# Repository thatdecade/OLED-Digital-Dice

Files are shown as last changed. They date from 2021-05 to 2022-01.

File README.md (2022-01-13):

# OLED-Digital-Dice

This project is based on the work of Joe Coburn for the original design and Fernando Hernandez (Dsk001) for the Wemos version.

This Electronic Die has the capability to swap between a coin and die with 4, 6, 8, 10, 12, and 20 sides and also a double 6 sided. Useful for table top gaming, or dice games that require two 6 sided die.

This version adds:
* Button debouncing
* Fixed randomizer
* Battery monitoring
* Shake sensor for dice rolls (Tilt switch)
* Auto Power Off (Deep Sleep)
* Neopixels
* Magic 8 Ball
* Supports both I2C and SPI displays

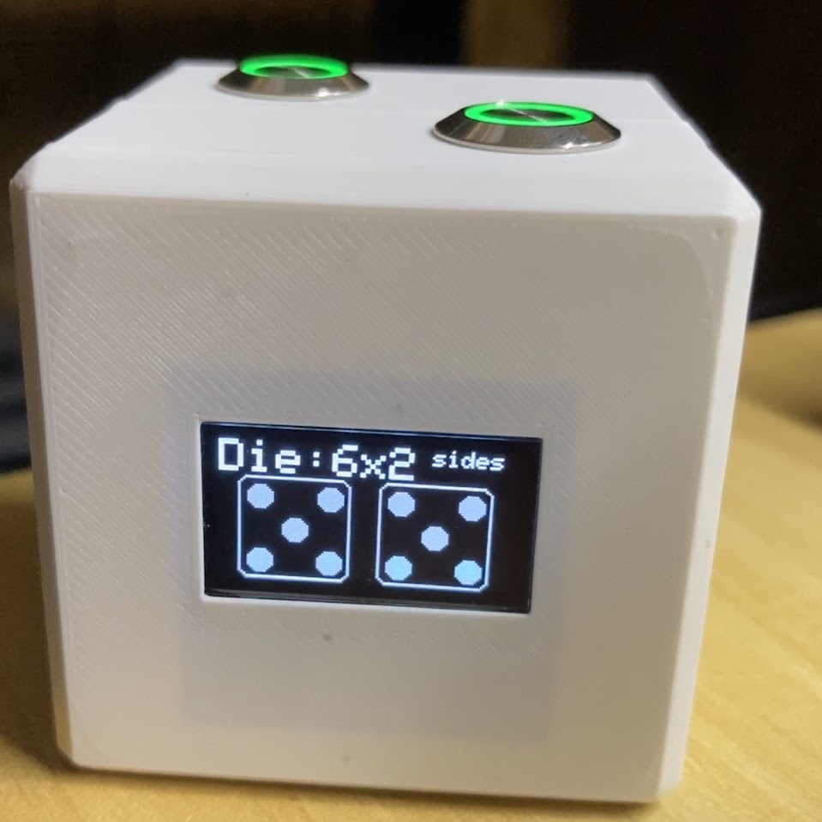
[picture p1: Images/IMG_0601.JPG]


Sources:
* 2017 Joe Coburn https://www.makeuseof.com/tag/roll-style-diy-electronic-d20/
* 2018 Tomas Carlsson (TomasC62) https://www.instructables.com/Arduino-Oled-Dice/
* 2021 Fernando Hernandez (Dsk001) https://www.prusaprinters.org/prints/66933-electronic-dice
* 2021 Joe Larson (3D Printing Professor) https://www.prusaprinters.org/prints/70261-electronic-dice-with-8-ball-function

# Hardware Used:

* 1 x D1 Mini (ESP8266, WiFi capable) https://amzn.to/3fCb4l7
* 1 x 0.96" I2C IIC SPI Serial 128x64 OLED screen https://amzn.to/3fxuOpV
* 2 x 12mm Push Buttons (LED optional) https://amzn.to/3p69FGo
* 2 x Metal Ball Tilt Switches (optional) https://amzn.to/34mlJKk

For battery operation (optional):

* 1 x Wemos D1 Battery Shield https://amzn.to/3c98Rvk
* 1 x 500mAh Lipo 
* 1 x 12mm LED Latching Push Button https://amzn.to/3uBmppL

We are a participant in the Amazon Services LLC Associates Program, an affiliate advertising program designed to provide a means for us to earn fees by linking to Amazon.com and affiliated sites.

# Printing:

Some openscad files are included in the project.  They assume you have downloaded the source files from https://www.prusaprinters.org/prints/66933-electronic-dice

* oled_face_mod.stl - The front shell oled area is trimmed to make it easier to fit.
* battery_back_mod.stl - The back shell includes cutaways for the battery shield, second usb connector, and a on/off push button.

# Pin References:

|Signal|In Type / Output Type|Label|GPIO|Input|Output|Notes|
|---|---|---|---|---|---|---|
|Deep Sleep Exit|Wire to RST|D0|GPIO16|no interrupt|no PWM or I2C support|HIGH at boot, used to wake up from deep sleep|
|Display SCL|I2C|D1|GPIO5|OK|OK|often used as (I2C)|
|Display SDA|I2C|D2|GPIO4|OK|OK|often used as (I2C)|
|Roll Button|Active Low Input|D3|GPIO0|pulled up|OK|connected to FLASH button, boot fails if pulled LOW|
|Die Button|Active High Input|D4|GPIO2|pulled up|OK|HIGH at boot, connected to on-board LED, boot fails if pulled LOW|
|Tilt Sensor 1|Active High Interrupt|D5|GPIO14|OK|OK|SPI (SCLK)|
|Roll LED|Active High Output|D6|GPIO12|OK|OK|SPI (MISO)|
|Neopixel Data|Data Output|D7|GPIO13|OK|OK|SPI (MOSI)|
|Dice LED|Active High Output|D8|GPIO15|pulled to GND|OK|SPI (CS), Boot fails if pulled HIGH|
|Tilt Sensor 2|Active High Interrupt|RX|GPIO3|OK|RX pin|HIGH at boot|
|||TX|GPIO1|TX pin|OK|HIGH at boot, debug output at boot, boot fails if pulled LOW|
|Battery Monitor|Analog Input|A0|ADC0|Analog Input|X||

Source: https://randomnerdtutorials.com/esp8266-pinout-reference-gpios/

# Assembly:

Wire up the following:

 *  D2(SDA), D1(SCL) to OLED
 *  D0 to RST
 *  D3 to Button (ROLL) to Ground
 *  D4 to Button (DIE) to 3.3V
 *  D5 to Tilt Sensor to Ground
 *  RX to Tilt Sensor to Ground
 *  D6 to Button (ROLL) LED to Ground
 *  D8 to Button (DIE) LED to Ground
 *  D7 to Neo Pixel Data (optional)
 *  A0 to Battery through Resistor Divider (optional)

If using the Battery Shield and you have v1.2.0 or higher, you can solder jumper J2 to connect the battery to A0 through a 130k resistor.
If not using a battery, comment out #define USE_BATTERY in code.

Test the circuit, then stuff into the 3D printed case.  Use hot glue or similar to affix the OLED.

Glue the tilt switch with the wires facing up, so the dice is only rolled when you shake it on it's side or upside down.
This prevents the number from changing while the dice is just sitting on the table.

# Programming:

You will need to add the d1 mini (esp8266) and LCD (SSD1306) to your Arduino IDE. Instructions here: https://github.com/esp8266/Arduino#installing-with-boards-manager

Select "NodeMCU 1.0 (ESP-12E Module)" from Tools > Board.

Program the board.

If you need more help: https://learn.adafruit.com/adafruit-huzzah-esp8266-breakout/using-arduino-ide

# Usage: 
 
*  Press ROLL button to roll dice.
*  Shake tilt sensors to roll dice.
*  Hold ROLL button to disable tilt sensors.
*  Press DICE button to change dice.
*  Hold DICE button to check battery info.

If USE_BATTERY was defined in code, after 15 minutes without a button press the dice will turn off the display and enter deep sleep.  Toggle the RST pin or turn off and on to wake up.

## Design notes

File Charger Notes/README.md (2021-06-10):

# Charger Notes

The wemos d1 is based on the ESP8266 and requires a voltage range of 2.6-3.6V.  The VIN pin can accept 4-6V.  Powering the wemos directly from a lipo cell is not recommended.  The fully charged voltage is over 4 volts.

If you look at the Wemos Battery Shield schematics, you will see that the charger IC has two functions: Charging the battery, and stepping up the voltage to 5V for the wemos. If you don't mind waiting, the battery shield is cheap to purchase from aliexpress. 

https://www.wemos.cc/en/latest/d1_mini_shield/battery.html

This article is for those who want to use their own battery charger.  You just need a charger, a step up regulator, Over-Discharge Protection, and a resistor divider.

--------------------

# Charger

I found TC4056A based USB C chargers for cheap on amazon. https://amzn.to/3uVuUw5

Documentation: https://www.addicore.com/TP4056-Charger-and-Protection-Module-p/ad310.htm

The default charing speed on this module is 1A.  That is a charge rate of 2C on a 500mAh lipo.  My lipo datasheet recommends 0.2-1C as the charging speed.
Swapping the R3 1.2k resistor for a 10k resistor will slow the charging down to a modest 130mA 0.2C.

# Step up Regulator

TBD

https://amzn.to/34X2uac - 5V step Up Circuit

# Over-Discharge Protection

The OUT+/- pins on the TC4056A charging module will give you Over-Discharge Protection.

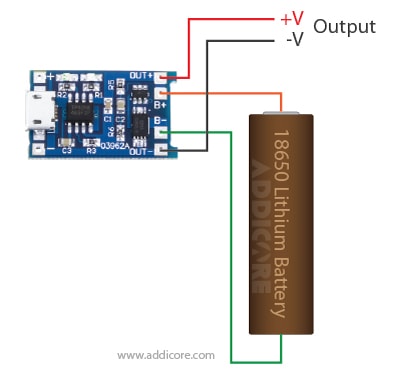
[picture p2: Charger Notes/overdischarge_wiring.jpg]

Source: https://www.addicore.com/TP4056-Charger-and-Protection-Module-p/ad310.htm

# Resistor Divider

To read the battery voltage on A0, you will need to divide it down to a voltage safe for the wemos to read.  My code expects a 130Kohm resistor in series with the battery to A0.  Refer to the link for calculating other resistances.

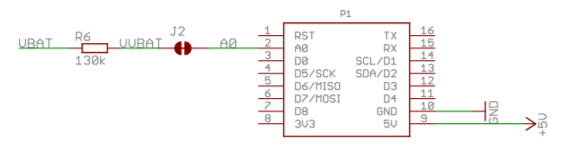
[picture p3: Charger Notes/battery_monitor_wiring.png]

Source: https://arduinodiy.wordpress.com/2016/12/25/monitoring-lipo-battery-voltage-with-wemos-d1-minibattery-shield-and-thingspeak/
	
# 3D Printing

Use the battery_back_mod_alt_charger files.
	
# Wiring

Battery -> (B) Charger (OUT) -> (IN) Step Up Regulator (OUT) -> On/Off Switch -> Wemos

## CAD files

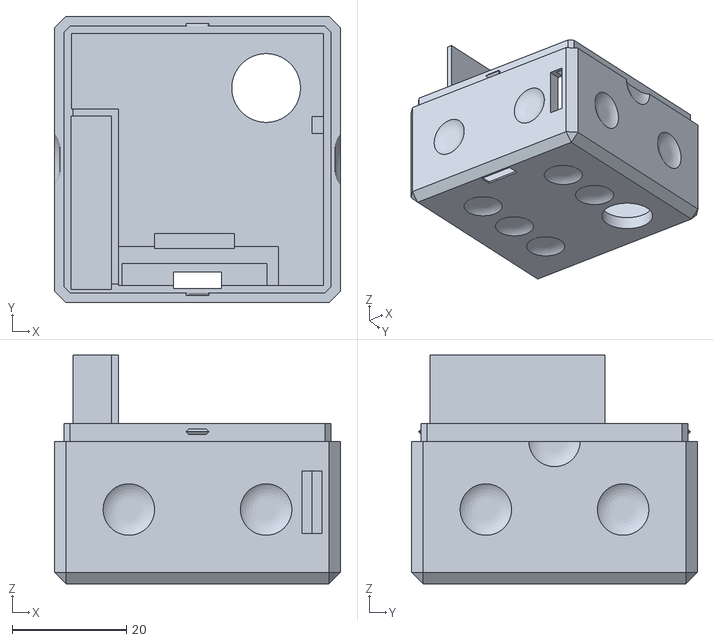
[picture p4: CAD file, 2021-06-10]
OpenSCAD/battery_back_mod_alt_charger_two_usb.obj
50.0 x 50.0 x 40.0

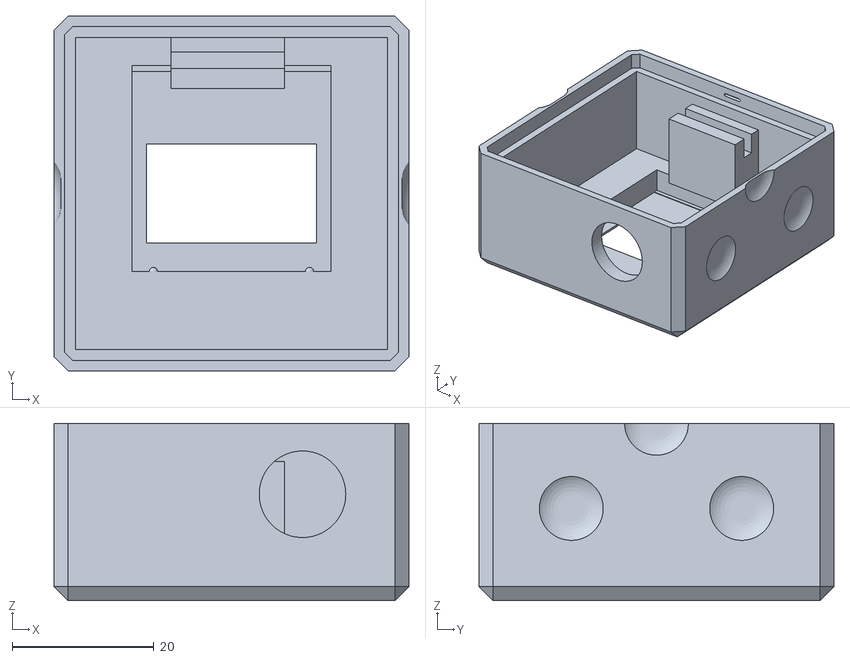
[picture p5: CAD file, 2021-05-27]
OpenSCAD/oled_face_mod.stl
50.0 x 50.0 x 25.0

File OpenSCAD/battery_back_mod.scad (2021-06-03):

/* Digital Dice - Facelift
 
   Author: Dustin Westaby

*/

cover_programming_usb = 0; //0 for uncovered, 1 for covered

sliding_fit = 2;
friction_fit = 0.2;

//dimensions
outer_shell_z = 25;

back_wall_thickness = 1.4; //1.3 //wemos usb is 2 layer heights, charger needs 6 layer heights
side_wall_thickness = 3;

battery_shield_distance_from_side_wall = 7;

switch_hole_diameter = 12;

usb_opening_width  = 8.5;
usb_opening_height = 3;
usb_x_offset_from_center = 5.75;
usb_y_offset_for_pcb_thickness = 1;

usb_board_width  = 23.66+2;
usb_board_height = 6.82+2;

battery_x = 5 + sliding_fit;
battery_y = 30 + friction_fit;
battery_z = 35 + sliding_fit;

battery_lid_wall_thickness = 1.2;
    
battery_y_offset = -0.6; //reduce overlap with die button clearance

//used to ensure wiring clearanceW
DIE_switch_x = 12 - 22;
DIE_switch_y = 30 + side_wall_thickness - friction_fit;
DIE_switch_z = 12;

difference()
{
    union()
    {
        translate([0,25,49.6]) rotate([-90,0,0]) import("back.stl");
        draw_battery_lid();
        if (cover_programming_usb) draw_usb_cover();
    }
    
    draw_charger_usb_slot();
    draw_charger_shield();
    draw_power_switch();
    translate([0,0,0]) draw_cord_cutin();

}

module draw_cord_cutin()
{
    cord_x = 10.8 + sliding_fit;
    cord_y = 6.8 + friction_fit;
    
    cutin_depth = back_wall_thickness - 0.4;
    
    translate([-cord_x/2-usb_x_offset_from_center,side_wall_thickness+battery_shield_distance_from_side_wall+usb_y_offset_for_pcb_thickness-cord_y/2+usb_opening_height/2,0]) cube([cord_x,cord_y,cutin_depth]);
}

module draw_usb_cover()
{
    translate([-usb_opening_width/2-0.5,back_wall_thickness+0.5,0]) cube([usb_opening_width+1,usb_opening_height+1,0.2]);
}

module draw_power_switch()
{
    //power switch hole
    translate([12,25/2*3,-0.1]) cylinder(h=4, d=switch_hole_diameter, $fn=100);
    
    //DIE switch clearance
    translate([0,0,3]) translate([DIE_switch_x,DIE_switch_y,DIE_switch_z]) rotate([-90,0,0]) cylinder(h=25, d=switch_hole_diameter, $fn=50);
    
    //battery clearance 
    translate([-22,3,3]) translate([-0.1,battery_y_offset-0.1,0.1]) cube([battery_x+0.1,battery_y+0.1,battery_z+0.1]);
}

module draw_charger_shield()
{
    inner_tab_thickness = 0.6;
    
    //battery board
    translate([-usb_board_width/2,side_wall_thickness+battery_shield_distance_from_side_wall-inner_tab_thickness,back_wall_thickness]) 
    cube([usb_board_width,usb_board_height+inner_tab_thickness,40], center=false);
}

module draw_charger_usb_slot()
{
    //usb slot
    translate([-usb_opening_width/2-usb_x_offset_from_center,side_wall_thickness+battery_shield_distance_from_side_wall+usb_y_offset_for_pcb_thickness,-0.1]) 
    cube([usb_opening_width,usb_opening_height,4], center=false);
        
}

module draw_battery_lid()
{
    //battery sleave / cover
    battery_x_wall = battery_x + battery_lid_wall_thickness;
    battery_y_wall = battery_y + battery_lid_wall_thickness;
    battery_z_wall = battery_z;

    translate([-22,3,3]) 
    difference() 
    {
        //shell
        cube([battery_x_wall,battery_y_wall+battery_y_offset,battery_z_wall]);
        
        //battery
        translate([-0.1,battery_y_offset-0.1,0.1]) cube([battery_x+0.1,battery_y+0.1,battery_z+0.1]);
        
        //chamfer sides to fit other shell
        translate([0,-0.1,outer_shell_z]) cube([battery_x_wall+0.1,friction_fit+0.1,battery_z_wall - outer_shell_z + 0.1]);
        translate([-0.1,0,outer_shell_z]) cube([friction_fit+0.1,battery_y_wall+0.1,battery_z_wall - outer_shell_z + 0.1]);
        
    }
}

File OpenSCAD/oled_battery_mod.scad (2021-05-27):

/* Digital Dice - Facelift
 
   Author: Dustin Westaby

*/

back_wall_thickness = 1.3;
side_wall_thickness = 2.4;

battery_shielf_distance_from_wemos_pcb = 11.06;

usb_opening_width  = 8.5;
usb_opening_height = 3;
usb_x_offset_from_center = 7;

usb_board_width  = 23.66+2;
usb_board_height = 6.82+2;

difference()
{
translate([0,25,49.6]) rotate([-90,0,0]) import("back.stl");

//usb slot
translate([-usb_opening_width/2-usb_x_offset_from_center,side_wall_thickness+battery_shielf_distance_from_wemos_pcb,-0.1]) cube([usb_opening_width,usb_opening_height,4], center=false);
    
    //battery board
translate([-usb_board_width/2,side_wall_thickness+battery_shielf_distance_from_wemos_pcb,back_wall_thickness]) cube([usb_board_width,usb_board_height,4], center=false);
    
translate([12,25/2*3,-0.1]) cylinder(h=4, d=12, $fn=100);
}

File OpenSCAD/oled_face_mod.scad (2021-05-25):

/* Digital Dice - Facelift
 
   Author: Dustin Westaby

   This script allows the dice face to be parameterized to fit any display size. 

*/

wall_thickness = 0.1;

old_display_size_x = 28;
old_display_size_y = 5;
old_display_size_z = 28;

//import("flexbatter1xAAAx3.stl");

translate([0,0,0.45]) rotate([90,0,0])
difference()
{
import("front.stl");

translate([0,old_display_size_y/2+wall_thickness,-4]) cube([old_display_size_x,old_display_size_y,old_display_size_z], center=true);
}

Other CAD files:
OpenSCAD/battery_back_mod_alt_charger_one_usb.obj
OpenSCAD/battery_back_mod_one_usb.stl
OpenSCAD/battery_back_mod_two_usb.stl
OpenSCAD/battery_back_mod_alt_charger.scad

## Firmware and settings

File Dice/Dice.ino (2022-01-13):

/* Electronic Dice:

    Author: Dustin Westaby
    Date: June 10, 2021

    Sources:
     - 2017 Joe Coburn (joecoburn) https://www.makeuseof.com/tag/roll-style-diy-electronic-d20/
     - 2018 Tomas Carlsson (TomasC62) https://www.instructables.com/Arduino-Oled-Dice/
     - 2021 Fernando Hernandez (Dsk001) https://www.prusaprinters.org/prints/66933-electronic-dice
     - 2021 Josh Segatto (alienslacker / alieneila) https://twitter.com/alienslacker/status/1398511306546765828

    Update the logo_bmp with your own image using LCDAssistant

    If you are not using a battery, comment out #define USE_BATTERY
    If you are not using a neopixel strip, comment out #define USE_NEOPIXELS

    Usage:
    Press ROLL button to roll dice.
    Shake upside down to roll dice (tilt sensors).
    Hold ROLL button to disable tilt sensors.
    Press DICE button to change dice.
    Hold DICE button to check battery info.
    
    LEDs are connected to D0 so they are forced off during Deep Sleep

*/


/* ************************************************* */

/* These are some top level options without touching main code */

// OPTIONS
//#define USE_SPI_OLED //comment or uncomment out the right communication
#define USE_IIC_OLED

#define USE_BATTERY //comment out to disable
#define MAX_BATTERY_VOLTAGE 4.2 //Use 4.5 for a 130k series resistor, use 4.2 for a 100k series resistor

#define NUMBER_OF_TILT_SENSORS 1 //up to 2, set to 0 to disable

#define NUMBER_OF_NEOPIXELS 0 //set to 0 to disable
#define TYPE_OF_NEOPIXELS (NEO_GRB + NEO_KHZ800)

#define ENABLE_MAGIC_8BALL

//#define ANIMATE_ROLLS

// TIMING
#define HOW_FAST_BUTTONS_AND_SCREEN_ARE_PROCESSED_IN_MS    100 // 100 = 10 Hz

#define DEEP_SLEEP_AFTER_THIS_MANY_MS_OF_INACTIVITY     900000 // 900,000 = 15 * 60 * 1000 = 15 mins

#define BUTTON_HOLD_DELAY_IN_MILLIS_UNTIL_HELD_ACTION     2000 // 2 seconds

#define RESERVE_POWER_PERCENT_FOR_SELF_SHUTDOWN 25 //percent

/* ************************************************* */

#include "Arduino.h"
#include <ESP8266WiFi.h>
#ifdef USE_IIC_OLED
#include <Wire.h>
#else
#include <SPI.h>
#endif
#include <Adafruit_GFX.h>
#include <Adafruit_SSD1306.h>

#if (NUMBER_OF_NEOPIXELS > 0)
#include <Adafruit_NeoPixel.h>
#endif

//Not all pins are interchangable, refer to https://randomnerdtutorials.com/esp8266-pinout-reference-gpios/

//These are the new pin outs
#ifdef USE_IIC_OLED
#define DISPLAY_SCL_PIN      5 // D1 - I2C
#define DISPLAY_SDA_PIN      4 // D2 - I2C
#define ROLL_BUTTON_PIN      0 // D3 - Active Low Input
#define DIE_BUTTON_PIN      15 // D8 - Active High Input
#define TILT_SENSOR_1_PIN   14 // D5 - Active High Interrupt
#define NEOPIXEL_DATA_PIN   13 // D7 - Data Output
#define TILT_SENSOR_2_PIN    3 // RX - Active High Interrupt
#define BATTERY_MONITOR_PIN A0 // A0 - Analog Input, Connect to battery through 130k resistor
#define BUTTON_LED_PIN      16 // D0 - Active High Output
#else //USE_SPI_OLED
#define OLED_MOSI           D7 // Wemos to D1 on OLED
#define OLED_CLK            D5 // Wemos to D0 on OLED 
#define OLED_CS             D2 // Wemos to CS on OLED
#define OLED_DC             D3 // Wemos to DC on OLED
#define OLED_RESET          D4 // Wemos to RES OLED
#define ROLL_BUTTON_PIN     D1 // Active Low Input
#define DIE_BUTTON_PIN      D8 // Active High Input
#define TILT_SENSOR_1_PIN    3 // RX, Active High Interrupt
#define BATTERY_MONITOR_PIN A0 // Analog Input, Connect to battery through 130k or 100k resistor
#define BUTTON_LED_PIN      D0 // Active High Output
//D6 = MISO
//TX = GPIO1
#endif

//screen config
#define SCREEN_WIDTH 128 // OLED display width, in pixels
#define SCREEN_HEIGHT 64 // OLED display height, in pixels

// Declaration for an SSD1306 display connected to I2C (SDA, SCL pins)
// The pins for I2C are defined by the Wire-library.
// On an arduino UNO:       A4(SDA), A5(SCL)
// On an arduino MEGA 2560: 20(SDA), 21(SCL)
// On an arduino LEONARDO:   2(SDA),  3(SCL),
// On a D1 Mini:             D2(SDA), D1(SCL)
#ifdef USE_IIC_OLED
#define OLED_RESET     -1 // Reset pin # (or -1 if sharing Arduino reset pin)
#define SCREEN_ADDRESS 0x3C ///< See datasheet for Address; 0x3D for 128x64, 0x3C for 128x32
Adafruit_SSD1306 display(SCREEN_WIDTH, SCREEN_HEIGHT, &Wire, OLED_RESET);
#else //USE_SPI_OLED
Adafruit_SSD1306 display(SCREEN_WIDTH, SCREEN_HEIGHT, OLED_MOSI, OLED_CLK, OLED_DC, OLED_RESET, OLED_CS);
#endif

#define LOGO_HEIGHT 43 //64
#define LOGO_WIDTH 128 //82
static const unsigned char PROGMEM logo_bmp[] =
{ //output from LCDAssistant, byte orientation: Horizontal
  0x00,0x00,0x00,0x00,0x00,0x00,0x00,0x00,0x00,0x00,0x00,0x00,0x00,0x00,0x00,0x00,0x00,0x00,0x00,0x00,0x00,0x00,0x00,0x00,0x01,0x80,0x00,0x00,0x00,0x00,0x00,0x00,0x00,0x00,0x00,0x00,0x00,0x00,0x38,0xFF,0xFF,0x80,0x00,0x00,0x00,0x00,0x00,0x00,0x00,0x00,0x7F,0xFF,0xFF,0xFF,0xF8,0xFF,0xFF,0x80,0x00,0x00,0x00,0x00,0x00,0x00,0x00,0x01,0xFF,0xFF,0xFF,0xFF,0xF8,0xFF,0xFF,0x80,0x00,0x00,0x00,0x00,0x00,0x00,0x00,0x01,0xFF,0x00,0x00,0x07,0xF8,0xFF,0xFF,0x9F,0xFF,0xFF,0xFF,0xFF,0xF0,0x00,0x40,0x01,0xFF,0x00,0x00,0x07,0xF8,0xFF,0xFF,0x9F,0xFF,0xFF,0xFF,0xFF,0xF0,0x00,0x38,0x39,0xFF,0xFF,0xFF,0xFF,0xF8,0xFF,0xFF,0x9F,0xFF,0xFF,0xFF,0xFF,0xF1,0xFC,0x03,0x39,0xFF,0xFF,0xFF,0xFF,0xF8,0xFF,0xFF,0x9F,0xFF,0xFF,0xFF,0xFF,0xF1,0xFE,0x00,0x01,0xFF,0xFF,0xFF,0xFF,0xF8,0xFF,0xFF,0x9F,0xFF,0xFF,0xFF,0xFF,0xF0,0x00,0x00,0x01,0xFF,0xFF,0xFF,0xFF,0xF8,0xFF,0xFF,0x9F,0xFF,0xFF,0xFF,0xFF,0xF0,0x00,0x00,0x01,0xFF,0xFF,0xFF,0xFF,0xF8,0xFF,0xFF,0x9F,0xFF,0xFF,0xFF,0xFF,0xF0,0x00,0x00,0x01,0xFF,0xFF,0xFF,0xFF,0xF8,0xFF,0xFF,0x80,0x00,0x00,0x00,0x00,0x00,0x00,0x00,0x00,0x7F,0xFF,0xFF,0xFF,0xF8,0xFF,0xFF,0x80,0x00,0x00,0x00,0x00,0x00,0x00,0x00,0x00,0x00,0x00,0x00,0x01,0xF8,0xFF,0xFF,0x80,0x00,0x00,0x00,0x00,0x00,0x00,0x00,0x00,0x00,0x00,0x00,0x00,0x00,0x00,0x07,0x80,0x00,0x00,0x00,0x00,0x00,0x00,0x00,0x00,0x00,0x00,0x00,0x00,0x00,0x00,0x00,0x80,0x00,0x00,0x00,0x00,0x00,0x00,0x00,0x00,0x00,0x00,0x00,0x00,0x00,0x00,0x00,0x00,0x00,0x00,0x00,0x00,0x00,0x00,0x00,0x00,0x00,0x00,0x00,0x00,0x00,0x00,0x00,0x00,0x00,0x00,0x00,0x00,0x00,0x00,0x00,0x00,0x00,0x00,0x00,0x00,0x00,0x00,0x00,0x00,0x00,0x00,0x00,0x00,0x00,0x00,0x00,0x00,0x00,0x00,0x00,0x00,0x00,0x00,0x00,0x00,0x00,0x00,0x00,0x00,0x00,0x00,0x00,0x00,0x00,0x00,0x00,0x00,0x00,0x00,0x00,0x00,0x00,0x00,0x00,0x00,0x00,0x00,0x00,0x00,0x00,0x00,0x00,0x00,0x00,0x00,0x00,0x00,0x00,0x00,0x00,0x00,0x00,0x00,0x60,0x1C,0x03,0x0F,0xFF,0x00,0xFC,0x1F,0xFF,0xE0,0x1C,0x00,0xFE,0x00,0xC0,0x06,0x60,0x1C,0x03,0x0F,0xFF,0x03,0xCF,0x1F,0xFF,0xE0,0x1C,0x00,0xFF,0xE0,0x60,0x0E,0x60,0x1C,0x03,0x0C,0x00,0x06,0x01,0x00,0x30,0x00,0x3C,0x00,0xC0,0x70,0x30,0x0C,0x60,0x34,0x06,0x0C,0x00,0x06,0x00,0x00,0x30,0x00,0x36,0x00,0xC0,0x30,0x30,0x18,0x30,0x36,0x06,0x0C,0x00,0x0C,0x00,0x00,0x30,0x00,0x26,0x00,0xC0,0x18,0x18,0x30,0x30,0x26,0x06,0x0C,0x00,0x0C,0x00,0x00,0x30,0x00,0x63,0x00,0xC0,0x18,0x0C,0x30,0x30,0x22,0x06,0x0C,0x00,0x0E,0x00,0x00,0x30,0x00,0x63,0x00,0xC0,0x30,0x0C,0x60,0x30,0x62,0x0C,0x0C,0x00,0x07,0x00,0x00,0x30,0x00,0xC1,0x00,0xC0,0x30,0x06,0xC0,0x18,0x63,0x0C,0x0F,0xFF,0x03,0xE0,0x00,0x30,0x00,0xC1,0x80,0xFF,0xC0,0x03,0xC0,0x18,0x43,0x0C,0x0F,0xFF,0x01,0xFE,0x00,0x30,0x00,0x81,0x80,0xFF,0xC0,0x03,0x80,0x18,0x41,0x0C,0x0C,0x00,0x00,0x0F,0x00,0x30,0x01,0x80,0x80,0xC0,0x30,0x01,0x80,0x18,0xC1,0x18,0x0C,0x00,0x00,0x03,0x80,0x30,0x01,0x80,0xC0,0xC0,0x18,0x01,0x80,0x0C,0xC1,0x98,0x0C,0x00,0x00,0x01,0x80,0x30,0x03,0x00,0xC0,0xC0,0x18,0x01,0x80,0x0C,0x81,0x98,0x0C,0x00,0x00,0x01,0x80,0x30,0x03,0xFF,0xE0,0xC0,0x18,0x01,0x80,0x0C,0x80,0x98,0x0C,0x00,0x00,0x01,0x80,0x30,0x03,0x00,0x60,0xC0,0x18,0x01,0x80,0x0D,0x80,0x90,0x0C,0x00,0x00,0x01,0x80,0x30,0x06,0x00,0x20,0xC0,0x18,0x01,0x80,0x07,0x80,0xF0,0x0C,0x00,0x08,0x03,0x80,0x30,0x06,0x00,0x30,0xC0,0x38,0x01,0x80,0x07,0x00,0xF0,0x0F,0xFF,0x0F,0x07,0x00,0x30,0x0C,0x00,0x30,0xFF,0xF0,0x01,0x80,0x07,0x00,0x70,0x0F,0xFF,0x03,0xFC,0x00,0x30,0x0C,0x00,0x18,0xFF,0xC0,0x01,0x80,0x00,0x00,0x00,0x00,0x00,0x00,0x00,0x00,0x00,0x00,0x00,0x00,0x00,0x00,0x00,0x00
};

#if (NUMBER_OF_NEOPIXELS > 0)
Adafruit_NeoPixel strip = Adafruit_NeoPixel(NUMBER_OF_NEOPIXELS, NEOPIXEL_DATA_PIN, TYPE_OF_NEOPIXELS);
int started = 0;
#endif

//variables
int curDie = 6; //Variable to select which die to use
#ifdef ENABLE_MAGIC_8BALL
int die[] = {2, 4, 6, 8, 10, 12, 64, 20, 7}; // 7 = 2D6, 64 = Magic 8 ball.
int numDie = 9;
char *magic8Answers[] = {
  "    It is certain", 
  "  It is decidedly so", 
  "    Without a doubt", 
  "    Yes definitely", 
  "  You may rely on it",
  "   As I see it, yes", 
  "      Most likely", 
  "     Outlook good", 
  "          Yes", 
  "   Signs point to yes", 
  "    Reply hazy, try          again", 
  "    Ask again later", 
  "  Better not tell you         now", 
  "   Cannot predict now", 
  "  Concentrate and ask        again", 
  "   Don't count on it", 
  "    My reply is no", 
  "   My sources say no", 
  "  Outlook not so good", 
  "     Very doubtful"
  };
int numMagic8Answers = 20;
#else
int die[] = {2, 4, 6, 8, 10, 12, 20, 7};
int numDie = 8;
#endif

#ifdef ANIMATE_ROLLS
int animationTicker = 0;
#endif
/* ***************** */
//button routines
typedef enum switch_status { PROCESSED, NOT_PROCESSED, };
typedef enum switch_state  { IS_NOT_PRESSED, IS_PRESSED, WAS_RELEASED, IS_HELD, };
typedef enum input_type    { ACTIVE_HIGH, ACTIVE_LOW, ANALOG_THRESHOLD, ACTIVE_HIGH_NO_PULLUP, };
typedef enum switch_type   { PUSHBUTTON, TILT_SENSOR, };

enum button_link
{
  /* order of button_info list */
  ROLL_BUTTON = 0,
  DIE_SELECT_BUTTON,
#if NUMBER_OF_TILT_SENSORS > 0
  TILT_INPUT_1,
#endif
#if (NUMBER_OF_TILT_SENSORS > 1) && defined(USE_IIC_OLED)
  TILT_INPUT_2,
#endif
  /* keep at end of list */
  NUMBER_OF_BUTTONS,
};

typedef struct
{
  byte          pin;
  input_type    in_type;
  switch_state  state;
  switch_status status;
  long          last_interaction_timestamp;
  byte          last_button_read;
  byte          current_button_read;
  switch_type   sw_type;
} button_struct;

button_struct button_info[NUMBER_OF_BUTTONS] =
{
  { /* button_info[ROLL_BUTTON] */
    /* pin       = */ ROLL_BUTTON_PIN,
    /* in_type   = */ ACTIVE_LOW,
    /* state     = */ IS_NOT_PRESSED,
    /* status    = */ NOT_PROCESSED,
    /* timestamp = */ 0,
    /* last      = */ false,
    /* current   = */ false,
    /* sw_type   = */ PUSHBUTTON,
  },
  { /* button_info[DIE_SELECT_BUTTON] */
    /* pin       = */ DIE_BUTTON_PIN,
    /* in_type   = */ ACTIVE_HIGH_NO_PULLUP,
    /* state     = */ IS_NOT_PRESSED,
    /* status    = */ NOT_PROCESSED,
    /* timestamp = */ 0,
    /* last      = */ false,
    /* current   = */ false,
    /* sw_type   = */ PUSHBUTTON,
  },
#if NUMBER_OF_TILT_SENSORS > 0
  { /* button_info[TILT_INPUT_1] */
    /* pin       = */ TILT_SENSOR_1_PIN,
    /* in_type   = */ ACTIVE_HIGH,
    /* state     = */ IS_NOT_PRESSED,
    /* status    = */ NOT_PROCESSED,
    /* timestamp = */ 0,
    /* last      = */ false,
    /* current   = */ false,
    /* sw_type   = */ TILT_SENSOR,
  },
#endif
#if (NUMBER_OF_TILT_SENSORS > 1) && defined(USE_IIC_OLED)
  {                /* button_info[TILT_INPUT_2] */
  /* pin       = */ TILT_SENSOR_2_PIN,
  /* in_type   = */ ACTIVE_HIGH,
  /* state     = */ IS_NOT_PRESSED,
  /* status    = *//NOT_PROCESSED,
  /* timestamp = */ 0,
  /* last      = */ false,
  /* current   = */ false,
  /* sw_type   = */ TILT_SENSOR,
  },
#endif
};

/* ***************** */

byte roll_flag = false;
byte tilt_flag = false;
byte tilt_enabled = true;

byte activity_flag = true;

#ifndef USE_BATTERY
ADC_MODE(ADC_VCC);
#endif

void setup()
{
  //setup output to serial monitor
  Serial.begin(115200);

#if (NUMBER_OF_NEOPIXELS > 0)
  strip.begin();
  strip.setBrightness(50);
  strip.show(); // Initialize all pixels to 'off'
#endif

  Serial.println(F("Digital Dice v1.0"));

  // SSD1306_SWITCHCAPVCC = generate display voltage from 3.3V internally
#ifdef USE_IIC_OLED
  if (!display.begin(SSD1306_SWITCHCAPVCC, SCREEN_ADDRESS))
#else //USE_SPI_OLED
  if(!display.begin(SSD1306_SWITCHCAPVCC))
#endif
  {
    Serial.println(F("Display driver failed"));
    for (;;); // Don't proceed, loop forever
  }

  // Clear the display buffer
  display.clearDisplay();

  // initialize the button pins as an input:
  for (byte i = 0; i < NUMBER_OF_BUTTONS; i++)
  {
    if (button_info[i].in_type == ACTIVE_HIGH_NO_PULLUP)
    {
      pinMode(button_info[i].pin, INPUT); //special pin, Active = 3.3V
    }
    else
    {
      pinMode(button_info[i].pin, INPUT_PULLUP);
    }

#if NUMBER_OF_TILT_SENSORS > 0
    //start die rollers
    if (button_info[i].sw_type == TILT_SENSOR)
    {
      attachInterrupt(digitalPinToInterrupt(button_info[i].pin), handle_tilt_interrupt, CHANGE);
    }
#endif

  }

#ifndef USE_BATTERY
  pinMode(BATTERY_MONITOR_PIN, INPUT); //battery monitor, add solder jumper to J2 on the v1.2.0 battery shield. See https://arduinodiy.wordpress.com/2016/12/25/monitoring-lipo-battery-voltage-with-wemos-d1-minibattery-shield-and-thingspeak/
#endif

  pinMode(BUTTON_LED_PIN, OUTPUT);
  digitalWrite(BUTTON_LED_PIN, HIGH);

  display.fillScreen(BLACK); // erase the whole display
  display.drawBitmap((SCREEN_WIDTH - LOGO_WIDTH) / 2, (SCREEN_HEIGHT - LOGO_HEIGHT) / 2, logo_bmp, LOGO_WIDTH, LOGO_HEIGHT, 1);
  display.display();
  delay(2000);

  display.fillScreen(BLACK);
  drawNameOfDie();
  drawShapeOfDie();
  display.display();

  WiFi.mode(WIFI_OFF); //We spend most of our time in light sleep with the radio off

  Serial.println(F("Startup Complete."));
}

void loop()
{

#if (NUMBER_OF_NEOPIXELS > 0)
  if ( started == 0 ) {
    colorWipe(strip.Color(0, 255, 0), 50); // Green
    started++;
  }
#endif

  //button and LED stuff
  poll_input_signals();
  process_button_presses();
  //process_led_state();

  //roll the dice when requested
  if (roll_flag || (tilt_flag && tilt_enabled))
  {
#ifdef ANIMATE_ROLLS
    animationTicker = 7;
  }
  if(animationTicker)
  {
    animationTicker--;
#endif
    process_roll_request();
    roll_flag = false;
    tilt_flag = false;
  }

  //power savings
  //check for activity timeout, then light sleep until the next poll interval
  check_for_inactivity_then_power_down();
  //check_for_low_battery_then_power_down();
  sleep_for_poll_rate(HOW_FAST_BUTTONS_AND_SCREEN_ARE_PROCESSED_IN_MS);

} //end loop

void callback() {
  Serial.flush();
}

void setup_text_to_display(int text_color, int text_size, int cursor_x, int cursor_y)
{
  display.setTextColor(text_color);
  display.setTextSize(text_size);
  display.setCursor(cursor_x, cursor_y);
}

void check_for_low_battery_then_power_down()
{
#ifdef USE_BATTERY
  static byte shutdown_timer = 10;
  
  float percent = get_battery_percent();

  if (percent < RESERVE_POWER_PERCENT_FOR_SELF_SHUTDOWN)
  {
    if (shutdown_timer > 0)
    {
      display_voltage();
    }
    else
    {
      turn_off_oled_and_deep_sleep();
    }
    shutdown_timer--;
  }
#endif
}

void check_for_inactivity_then_power_down()
{
  static long last_activity = 0;

  if (activity_flag)
  {
    activity_flag = false;
    last_activity = millis();
  }

  if (millis() >= (last_activity + DEEP_SLEEP_AFTER_THIS_MANY_MS_OF_INACTIVITY - 10000))
  {
    long seconds = ( (last_activity + DEEP_SLEEP_AFTER_THIS_MANY_MS_OF_INACTIVITY) - millis() ) / 1000;
    shutdown_message(seconds);
  }

  if (millis() >= (last_activity + DEEP_SLEEP_AFTER_THIS_MANY_MS_OF_INACTIVITY))
  {
    turn_off_oled_and_deep_sleep();
  }
}

void shutdown_message(long seconds)
{
  Serial.printf("Inactive for %ld minutes. Shutting down in %ld seconds.\n", DEEP_SLEEP_AFTER_THIS_MANY_MS_OF_INACTIVITY / 60000, seconds / 1000);

  display.fillScreen(BLACK); // erase the whole display
  setup_text_to_display(/* color = */ WHITE, /* size = */ 1, /* x = */ 0, /* y = */ 0);
  display.print("Shutting Down in");

  setup_text_to_display(/* color = */ WHITE, /* size = */ 2, /* x = */ 0, /* y = */ 18);
  display.print(seconds);

  setup_text_to_display(/* color = */ WHITE, /* size = */ 1, /* x = */ 0, /* y = */ 44);
  display.print("seconds.");

  setup_text_to_display(/* color = */ WHITE, /* size = */ 2, /* x = */ 0, /* y = */ 56);
  if (tilt_enabled)
  {
    display.print("Shake dice to stop.");
  }
  else
  {
    display.print("Press any button to stop.");
  }
  display.display(); // write to display
}

void turn_off_oled_and_deep_sleep()
{
  digitalWrite(BUTTON_LED_PIN, LOW);

  display.fillScreen(BLACK); // erase the whole display
  setup_text_to_display(/* color = */ WHITE, /* size = */ 1, /* x = */ 0, /* y = */ 0);
  display.print("Shutting Down");

  setup_text_to_display(/* color = */ WHITE, /* size = */ 2, /* x = */ 0, /* y = */ 24);
  display.print("Good Bye");
  display.display(); // write to display
  delay(1000);

  display.fillScreen(BLACK); // erase the whole display
  display.display(); // write to display

  //For this to work, connect D0 and RST pins with a jumper wire.
  Serial.println("Enter deep sleep mode");
  ESP.deepSleep(0, RF_DISABLED);
}

void sleep_for_poll_rate(long rate)
{
  //Source: https://www.mischianti.org/2019/11/21/wemos-d1-mini-esp8266-the-three-type-of-sleep-mode-to-manage-energy-savings-part-4/

  // Enter light sleep mode

  wifi_set_opmode(NULL_MODE);
  wifi_fpm_set_sleep_type(LIGHT_SLEEP_T);
  wifi_fpm_open();
  wifi_fpm_set_wakeup_cb(callback);
  wifi_fpm_do_sleep(rate * 1000 );
  delay(rate + 1);

  // Exit light sleep mode

  wifi_set_sleep_type(NONE_SLEEP_T);
}

#if NUMBER_OF_TILT_SENSORS > 0
ICACHE_RAM_ATTR void handle_tilt_interrupt()
{
  /* This function must be very short */
  tilt_flag = true;
}
#endif

#if NUMBER_OF_TILT_SENSORS > 0
void enable_disable_tilt()
{
  tilt_enabled = !tilt_enabled;
  display.fillScreen(BLACK); // erase the whole display
  setup_text_to_display(/* color = */ WHITE, /* size = */ 1, /* x = */ 0, /* y = */ 0);
  display.print("Motion Roll");
  setup_text_to_display(/* color = */ WHITE, /* size = */ 1, /* x = */ 0, /* y = */ 12);
  if (tilt_enabled)
  {
    Serial.println("Tilt Enabled");
    display.print("Enabled");
    display.display(); // write to display
    delay(1000);
    display.setCursor(0, 24);
    display.print("Shake upside down to roll");
    display.display(); // write to display
  }
  else
  {
    Serial.println("Tilt Disabled");
    display.print("Disabled");
    display.display(); // write to display
    delay(1000);
    display.setCursor(0, 24);
    display.print("Press button to roll");
    display.display(); // write to display
  }
  delay(1000);
  display.fillScreen(BLACK);
  drawNameOfDie();
  drawShapeOfDie();
  display.display();
}
#endif

int get_random_number(int min, int max)
{
  //attempt to fix the RNG
  //this gives me a different number on sequential boots, and two dice side by side give different numbers
  randomSeed(ESP.getCycleCount());

  return random(min, max);
}

void process_roll_request()
{
  display.fillScreen(BLACK); // erase the whole display
  display.setTextColor(WHITE);
  display.setTextSize(3);
  int roll;
  int roll2 = 0;

#if (NUMBER_OF_NEOPIXELS > 0)
  colorWipe(strip.Color(0, 0, 255), 50); // Blue
#endif

  // store the random number
#ifdef ENABLE_MAGIC_8BALL
  if (die[curDie] == 64)
  {
     roll = random(0, numMagic8Answers); 
  }
  else if (die[curDie] == 7)
#else
  if (die[curDie] == 7)
#endif
  {
    roll = get_random_number(1, die[curDie]);
    roll2 = get_random_number(1, die[curDie]);
  }
  else
  {
    roll = get_random_number(1, die[curDie] + 1);
  }

#ifdef ENABLE_MAGIC_8BALL  
  if (die[curDie] == 64) 
  {
    drawShapeOfDie();
    drawNameOfDie();
    drawMagic8Ball(roll);
  } 
  else if (roll < 10)
#else
  if (roll < 10)
#endif
  {
    // single character number
    switch (die[curDie])
    {
      case 2:
      case 4:
        display.setCursor(57, 29);
        display.println(roll); // write the roll
        break;
      case 6:
        draw6(roll);
        break;
      case 7:
        draw2xD6(roll, roll2);
        break;
      case 8:
      case 10:
      case 12:
        display.setCursor(57, 32);
        display.println(roll); // write the roll
        break;
      case 20:
        display.setCursor(57, 22);
        display.println(roll); // write the roll
        break;
      // case 64: // Magic 8 Ball Case handled before switch statement
    }
    drawShapeOfDie(); // draw the outline
    drawNameOfDie();
  }
  else
  {
    // dual character number
    switch (die[curDie])
    {
      case 10:
      case 12:
        display.setCursor(47, 32);
        break;
      case 20:
        display.setCursor(47, 22);
        break;
    }

    display.println(roll); // write the roll
    drawShapeOfDie(); // draw the outline
    drawNameOfDie();
  }

  display.display(); // write to display

#if (NUMBER_OF_NEOPIXELS > 0)
  if (die[curDie] != 7)
  {
    if ( roll == 1 ) {
      theaterChase(strip.Color(127,   0,   0), 50); // Red
    }
    else if ( roll == 20 ) {
      rainbowCycle(20);
    }
    else {
      colorWipe(strip.Color(0, 255, 0), 50); // Green
    }
  } else
  {
    if ( roll + roll2 == 2 ) {
      theaterChase(strip.Color(127,   0,   0), 50); // Red
    }
    else {
      colorWipe(strip.Color(0, 255, 0), 50); // Green
    }
  }
#endif

}

void process_die_change_request()
{
  curDie++;
  if (curDie >= numDie)
  {
    curDie = 0;
  }
  display.fillScreen(BLACK);
  drawNameOfDie();
  drawShapeOfDie();
  display.display();
}
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

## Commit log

2021-05-25 Project files
    [oled_back_mod.scad, oled_face_mod.scad]
2021-05-25 Debugged tilt sensor.
2021-05-26 Added second redundant tilt sensor, fixed internal pull ups. Hold roll button to disable motion rolls.
    [Dice.ino]
2021-05-26 Added battery shield monitor, sleep drafted
2021-05-26 Finished sleep. Measures as 65mA idle. Added battery percent monitor
2021-05-27 Added 3d printing files
    [oled_back_mod.scad, oled_back_mod.stl, oled_face_mod.stl]
2021-05-27 Name changes
    [oled_battery_mod.scad, oled_battery_mod.stl]
2021-05-27 Name change
    [battery_back_mod.stl]
2021-06-02 Added protected battery shelf
    [battery_back_mod.scad, battery_back_mod.stl]
2021-06-02 New Button structures, support for previous pin wiring, better randomization
2021-06-02 Added #define for builds without tilt sensors
2021-06-02 Adjusted shield position to sit closer to the wemos
    [battery_back_mod.scad, battery_back_mod.stl]
2021-06-02 Adjust usb charger fit
    [battery_back_mod.scad, battery_back_mod.stl, battery_back_mod_two_usb.stl]
2021-06-03 widened area surrounding usb cable
    [battery_back_mod.scad, battery_back_mod_two_usb.stl]
2021-06-03 Covered programming usb port (use charger usb port)
    [battery_back_mod_one_usb.stl]
2021-06-07 Updated wiring after testing. Added code option to set number of tilt sensors (0-2)
2021-06-07 Added a software low voltage protection, in case your battery charger lacks low voltage protection.
2021-06-07 Thoughts on alternate chargers
2021-06-10 Alternate battery charger slot
    [battery_back_mod_alt_charger.scad, battery_back_mod_alt_charger_one_usb.obj, battery_back_mod_alt_charger_two_usb.obj]
2021-06-10 Added SPI OLED support, reduces tilt and LED io pins to 1 each
2021-07-22 Minor update to SPI display wiring
